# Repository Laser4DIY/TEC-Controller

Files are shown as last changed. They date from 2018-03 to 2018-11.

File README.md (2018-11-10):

# Laser4DIY TEC Controller

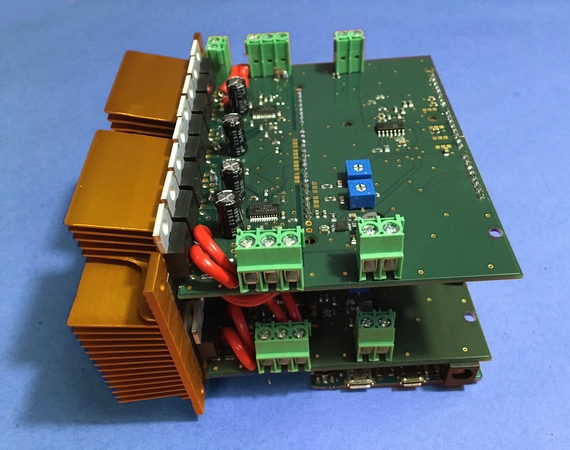
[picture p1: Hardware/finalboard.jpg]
TEC Controller board


This is the repository for the TEC (ThermoElectric Cooling) controller used in the [Laser4DIY project](http://www.laser4diy.org/).

## Specs

* Designed as a shield for the Arduino Due
* 2-channel TEC controller, driving peltier elements up to 106W heat transfer capacity per channel (12A at 15.5V)
* 2 boards can be stacked for a 4-channel TEC controller, driven by a single Arduino Due

## Repository Layout

```
+ Firmware                      firmware directory
| + Firmware.ino                Main Arduino firmware source code file
| + functions_PWM_DAC.ino       source code
| + LICENSE.txt                 license for the fimware
| + main_loop.ino               source code
| + main_setup.ino              source code
+ Hardware                      hardware directory
| + cern_ohl_v_1_2_howto.pdf    Howto for the used hardware license
| + CHANGES.txt                 list of hardware changes
| + finalboard.jpg              photo of the final board
| + LICENSE.txt                 license for the hardware
| + README.txt                  hardware readme
| + schematic.png               schematic
| + TEC-Controller.brd          board layout
| + TEC-Controller.sch          schematic
```

## Documentation

The TEC Controller is documented at [FabLab München Wiki](https://wiki.fablab-muenchen.de/display/WIKI/LASER4DIY+-+TEC+Controller).

## Known Issues

See [Open Issues](https://github.com/Laser4DIY/TEC-Controller/issues?utf8=%E2%9C%93&q=is%3Aopen+is%3Aissue).

## License

The hardware documentation is licensed under CERN OHL v.1.2.

The firmware is licensed under GPLv3.

For details see licensing info in the respective sub directories.

---

Copyright FabLab München e.V. 2018

Laser4DIY is sponsored by the Federal Ministry of Education and Research

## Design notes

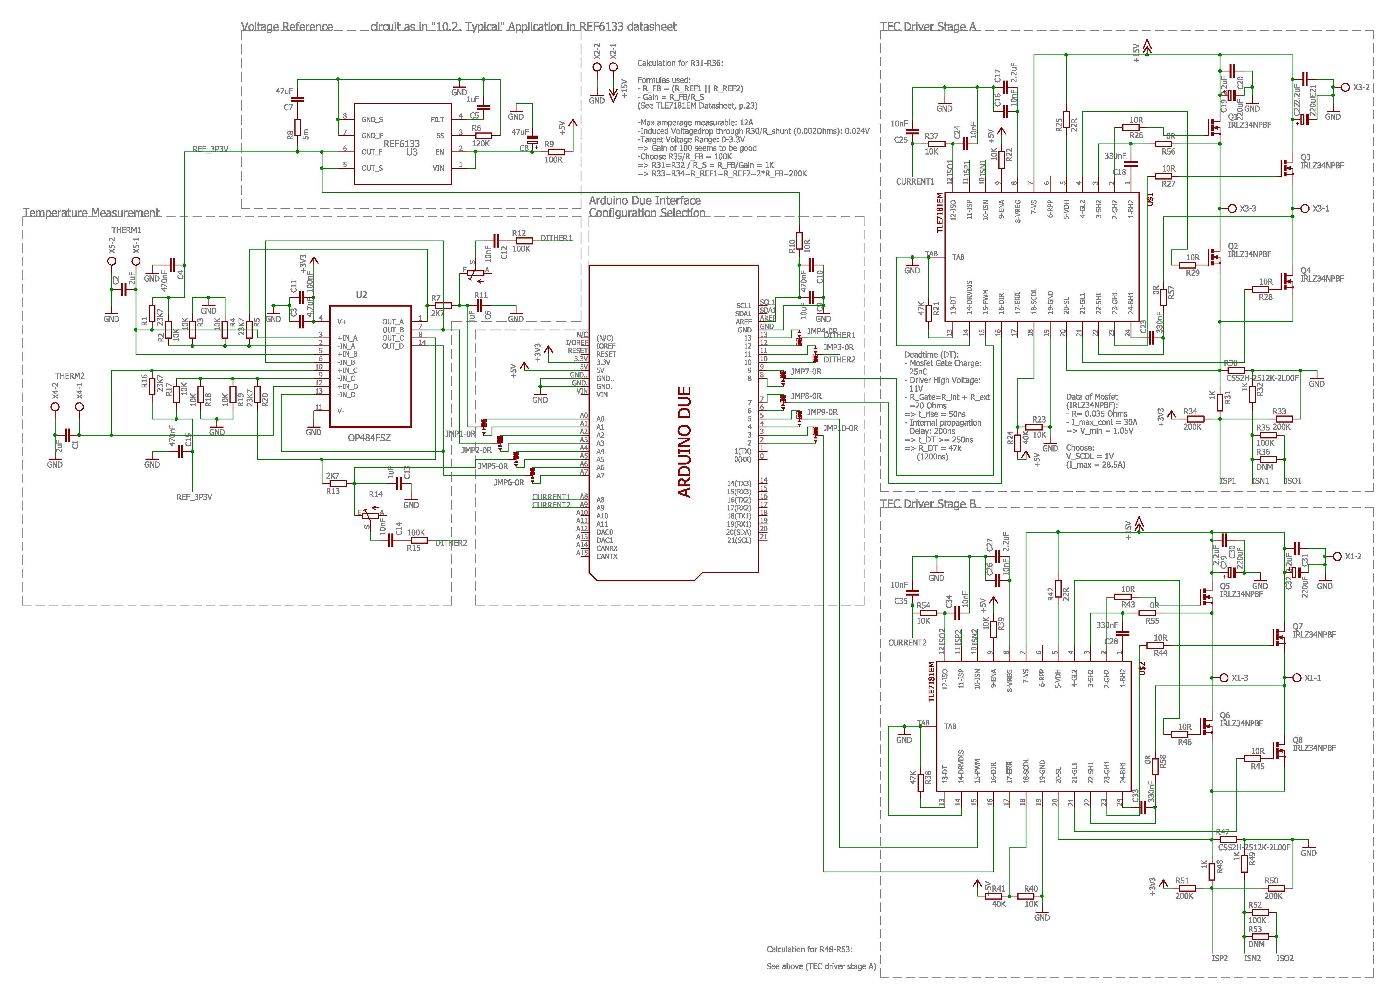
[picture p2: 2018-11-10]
Hardware/schematic.png

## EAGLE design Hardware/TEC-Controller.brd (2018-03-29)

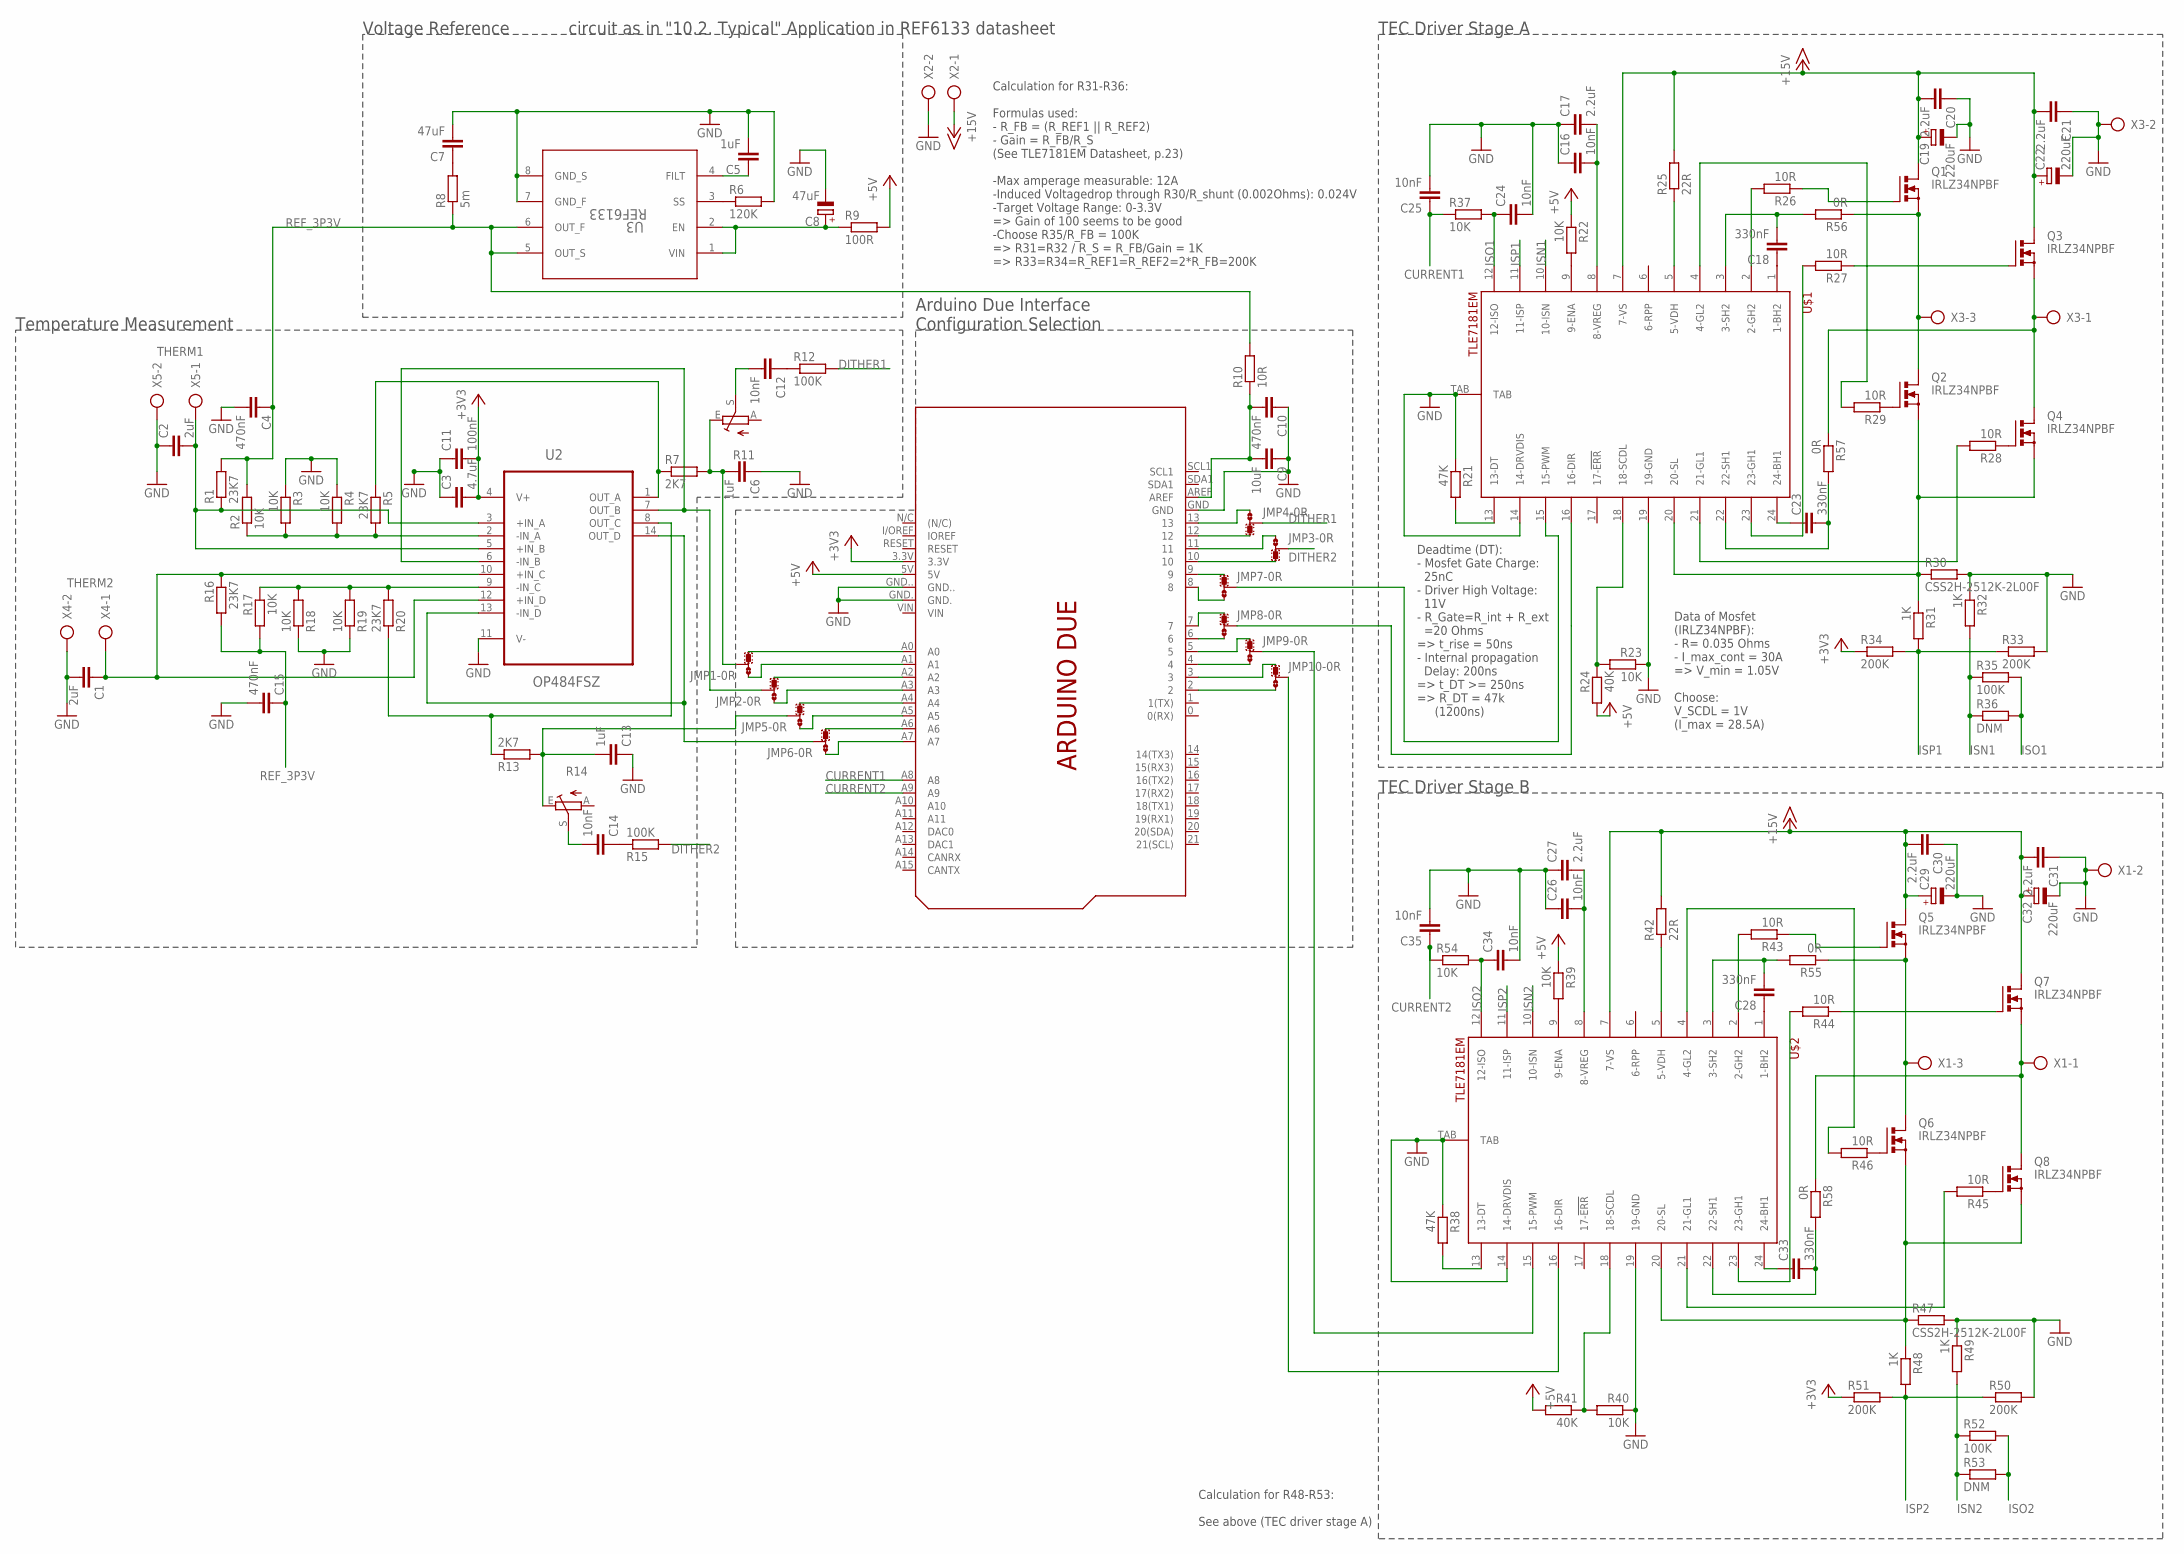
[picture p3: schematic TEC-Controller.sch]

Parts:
C1, C2: 2uF; C0805
C3: 4.7uF; C0603
C4: 470nF; C0805
C5, C6, C13: 1uF; C0805
C7: 47uF; C0603
C8: 47uF; PANASONIC_D
C9: 10uF; C0603
C10, C15: 470nF; C0603
C11: 100nF; C0603
C12, C14: 10nF; C0805
C16, C24, C25: 10nF; C0603K
C17, C20, C21, C30, C31: 2.2uF; C0603K
C18, C23, C28, C33: 330nF; C0603K
C19, C22, C29, C32: 220uF; E2,5-7
C26, C34, C35: 10nF; C0603
C27: 2.2uF; C0603
JMP1, JMP2, JMP3, JMP4, JMP5, JMP6, JMP7, JMP8, JMP9, JMP10: 0R-JUMPA; A0R-JMP
PCB1: ARDUINO_DUE_SHIELD
Q1, Q2, Q3, Q4, Q5, Q6, Q7, Q8: IRLZ34NPBF; TO220BV
R1: 23K7; R0603
R2, R3, R22, R23, R37, R39, R40, R54: 10K; R0603
R4, R17, R18, R19: 10K; R0805
R5, R16, R20: 23K7; R0805
R6: 120K; R0805
R7, R13: 2K7; R0805
R8: 5m; R0603
R9: 100R; R0805
R10, R26: 10R; R0805
R11, R14: TRIM_EU-B64W; B64W
R12, R15: 100K; R0805
R21, R38: 47K; R0603
R24, R41: 40K; R0603
R25, R42: 22R; R0603
R27, R28, R29, R43, R44, R45, R46: 10R; 0204/7
R30, R47: CSS2H-2512K-2L00F; R2512
R31, R32, R48, R49: 1K; R0603
R33, R34, R50, R51: 200K; R0603
R35, R52: 100K; R0603
R36, R53: DNM; R0603
R55, R56, R57, R58: 0R; 0204/7
U2: OP484FSZ; SOIC127P600X175-14N
U3: REF6133; DGK0008A_N
U$1, U$2: TLE7181EM; PG-SSOP-24-4
X1, X3: AK500/3
X2, X4, X5: AK500/2

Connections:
+3V3: C3.2, C11.2, PCB1.3.3V, R34.1, R51.1, U2.4 (V+)
+5V: PCB1.5V, R9.2, R22.1, R24.2, R39.1, R41.2
+15V: C19.+, C20.2, C21.2, C22.+, C29.+, C30.2, C31.2, C32.+, Q1.D, Q3.D, Q5.D, Q7.D, R25.2, R42.2, U$1.7 (7-VS), U$2.7 (7-VS), X2.1
CURRENT1: C25.1, PCB1.A8, R37.1
CURRENT2: C35.1, PCB1.A9, R54.1
DITHER1: JMP4.2, R12.2
DITHER2: JMP3.2, R15.2
GND: C1.2, C2.1, C3.1, C4.2, C5.2, C6.1, C7.2, C8.-, C9.1, C10.1, C11.1, C13.1, C15.2, C16.1, C17.1, C19.-, C20.1, C21.1, C22.-, C24.2, C25.2, C26.1, C27.1, C29.-, C30.1, C31.1, C32.-, C34.2, C35.2, PCB1.GND, PCB1.GND., PCB1.GND.., R3.1, R4.1, R6.2, R18.1, R19.1, R21.1, R23.1, R30.2, R32.1, R33.2, R38.1, R40.1, R47.2, R49.1, R50.2, U2.11 (V-), U3.7 (GND_F), U3.8 (GND_S), U$1.14 (14-DRVDIS), U$1.19 (19-GND), U$1.TAB, U$2.14 (14-DRVDIS), U$2.19 (19-GND), U$2.TAB, X1.2, X2.2, X3.2, X4.2, X5.2
ISN1: R32.2, R35.1, R36.1, U$1.10 (10-ISN)
ISN2: R49.2, R52.1, R53.1, U$2.10 (10-ISN)
ISO1: C24.1, R35.2, R36.2, R37.2, U$1.12 (12-ISO)
ISO2: C34.1, R52.2, R53.2, R54.2, U$2.12 (12-ISO)
ISP1: R31.2, R33.1, R34.2, U$1.11 (11-ISP)
ISP2: R48.2, R50.1, R51.2, U$2.11 (11-ISP)
unnamed: C28.2, R55.2, U$2.3 (3-SH2)
unnamed: C2.2, R1.1, U2.3 (+IN_A), U2.5 (+IN_B), X5.1
unnamed: C1.1, R16.1, U2.10 (+IN_C), U2.12 (+IN_D), X4.1
unnamed: R2.1, R3.2, R4.2, R5.2, U2.2 (-IN_A)
unnamed: C18.2, R56.2, U$1.3 (3-SH2)
unnamed: JMP2.2, U2.6 (-IN_B), U2.7 (OUT_B)
unnamed: R5.1, R7.1, U2.1 (OUT_A)
unnamed: JMP4.3, PCB1.12
unnamed: JMP1.3, PCB1.A0
unnamed: C5.1, U3.4 (FILT)
unnamed: R6.1, U3.3 (SS)
unnamed: JMP1.1, PCB1.A1
unnamed: JMP2.3, PCB1.A2
unnamed: C6.2, JMP1.2, R7.2, R11.E
unnamed: JMP2.1, PCB1.A3
unnamed: C7.1, R8.2
unnamed: C8.+, R9.1, U3.1 (VIN), U3.2 (EN)
unnamed: C9.2, C10.2, PCB1.AREF, R10.1
unnamed: C12.2, R11.S
unnamed: JMP3.1, PCB1.11
unnamed: JMP4.1, PCB1.13
unnamed: JMP7.1, PCB1.9
unnamed: JMP3.3, PCB1.10
unnamed: C12.1, R12.1
unnamed: R17.1, R18.2, R19.2, R20.2, U2.9 (-IN_C)
unnamed: R13.1, R20.1, U2.8 (OUT_C)
unnamed: C13.2, JMP5.2, R13.2, R14.E
unnamed: C14.1, R15.1
unnamed: C14.2, R14.S
unnamed: JMP5.3, PCB1.A4
unnamed: JMP5.1, PCB1.A5
unnamed: JMP7.3, PCB1.8
unnamed: JMP6.3, PCB1.A6
unnamed: JMP6.1, PCB1.A7
unnamed: JMP6.2, U2.13 (-IN_D), U2.14 (OUT_D)
unnamed: JMP8.1, PCB1.7
unnamed: JMP8.3, PCB1.6
unnamed: JMP7.2, U$1.15 (15-PWM)
unnamed: JMP8.2, U$1.16 (16-DIR)
unnamed: R21.2, U$1.13 (13-DT)
unnamed: R23.2, R24.1, U$1.18 (18-SCDL)
unnamed: R22.2, U$1.9 (9-ENA)
unnamed: R25.1, U$1.5 (5-VDH)
unnamed: C16.2, C17.2, U$1.8 (8-VREG)
unnamed: R26.2, U$1.2 (2-GH2)
unnamed: Q1.G, R26.1
unnamed: Q1.S, Q2.D, R56.1, X3.3
unnamed: C18.1, U$1.1 (1-BH2)
unnamed: R27.2, U$1.23 (23-GH1)
unnamed: Q3.G, R27.1
unnamed: Q3.S, Q4.D, R57.1, X3.1
unnamed: C23.1, U$1.24 (24-BH1)
unnamed: Q4.G, R28.1
unnamed: Q2.G, R29.1
unnamed: R29.2, U$1.4 (4-GL2)
unnamed: R28.2, U$1.21 (21-GL1)
unnamed: Q2.S, Q4.S, R30.1, R31.1, U$1.20 (20-SL)
unnamed: JMP9.2, U$2.15 (15-PWM)
unnamed: C33.2, R58.2, U$2.22 (22-SH1)
unnamed: JMP10.2, U$2.16 (16-DIR)
unnamed: R38.2, U$2.13 (13-DT)
unnamed: R39.2, U$2.9 (9-ENA)
unnamed: R40.2, R41.1, U$2.18 (18-SCDL)
unnamed: C26.2, C27.2, U$2.8 (8-VREG)
unnamed: R42.1, U$2.5 (5-VDH)
unnamed: R43.2, U$2.2 (2-GH2)
unnamed: Q5.S, Q6.D, R55.1, X1.3
unnamed: C28.1, U$2.1 (1-BH2)
unnamed: Q5.G, R43.1
unnamed: R44.2, U$2.23 (23-GH1)
unnamed: Q7.G, R44.1
unnamed: Q7.S, Q8.D, R58.1, X1.1
unnamed: C33.1, U$2.24 (24-BH1)
unnamed: Q8.G, R45.1
unnamed: Q6.G, R46.1
unnamed: R46.2, U$2.4 (4-GL2)
unnamed: R45.2, U$2.21 (21-GL1)
unnamed: Q6.S, Q8.S, R47.1, R48.1, U$2.20 (20-SL)
unnamed: C23.2, R57.2, U$1.22 (22-SH1)
unnamed: JMP9.1, PCB1.5
unnamed: JMP9.3, PCB1.4
unnamed: JMP10.1, PCB1.3
unnamed: JMP10.3, PCB1.2
REF_3P3V: C4.1, C15.1, R1.2, R2.2, R8.1, R10.2, R16.2, R17.2, U3.5 (OUT_S), U3.6 (OUT_F)

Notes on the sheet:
THERM1
THERM2
Voltage Reference
Temperature Measurement
Arduino Due Interface Configuration Selection
TEC Driver Stage A
TEC Driver Stage B
circuit as in "10.2. Typical" Application in REF6133 datasheet
Calculation for R31-R36: Formulas used: - R_FB = (R_REF1 || R_REF2) - Gain = R_FB/R_S (See TLE7181EM Datasheet, p.23) -Max amperage measurable: 12A -Induced Voltagedrop through R30/R_shunt (0.002Ohms): 0.024V -Target Voltage Range: 0-3.3V => Gain of 100 seems to be good -Choose R35/R_FB = 100K => R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
Calculation for R48-R53: See above (TEC driver stage A)
Data of Mosfet (IRLZ34NPBF): - R= 0.035 Ohms - I_max_cont = 30A => V_min = 1.05V Choose: V_SCDL = 1V (I_max = 28.5A)
Deadtime (DT): - Mosfet Gate Charge: 25nC - Driver High Voltage: 11V - R_Gate=R_int + R_ext =20 Ohms => t_rise = 50ns - Internal propagation Delay: 200ns => t_DT >= 250ns => R_DT = 47k (1200ns)

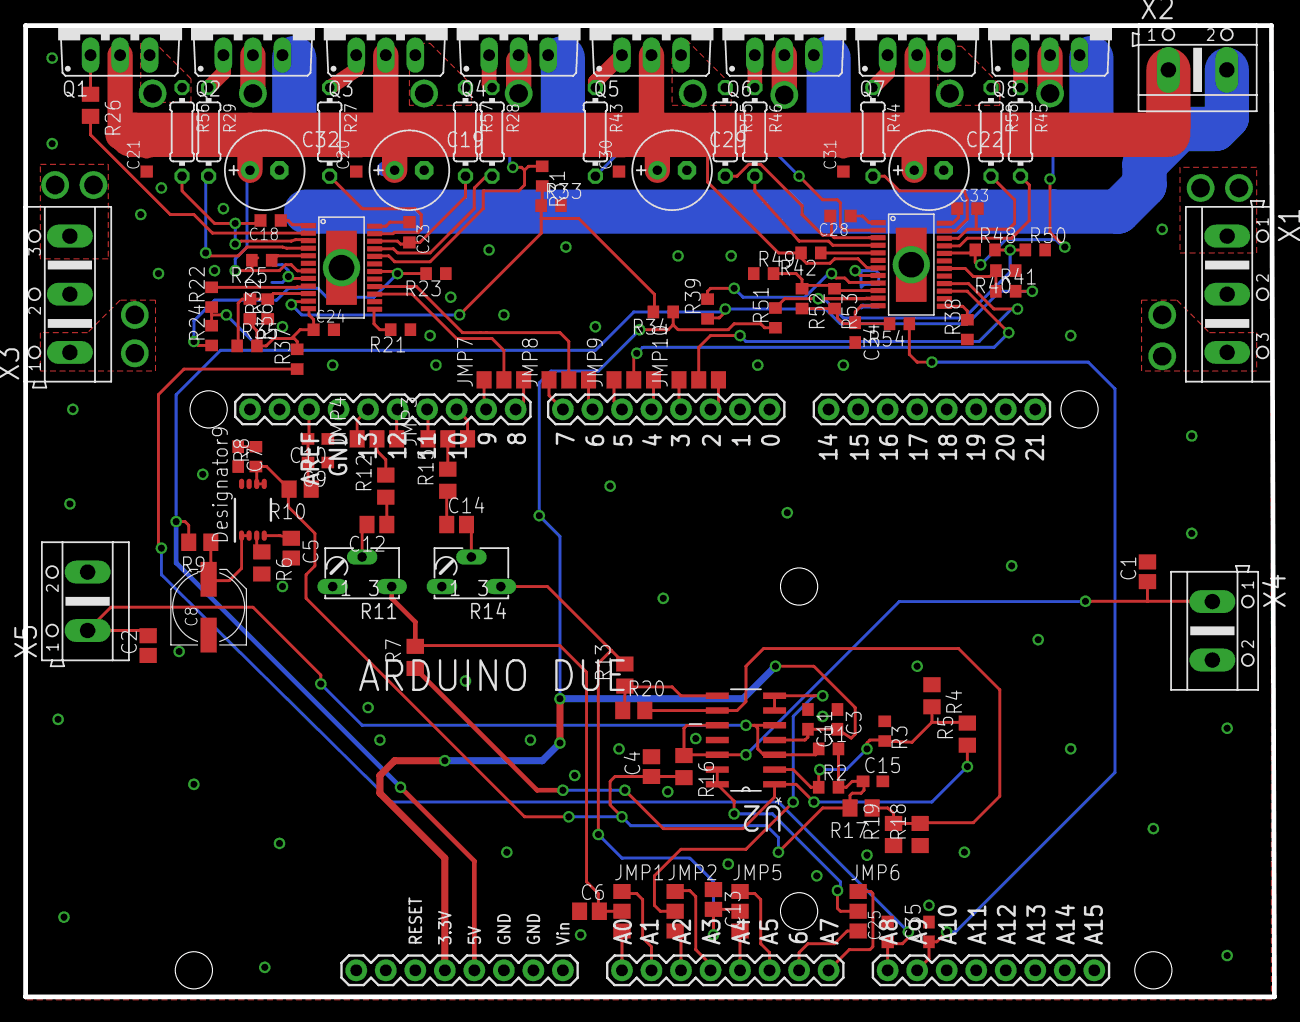
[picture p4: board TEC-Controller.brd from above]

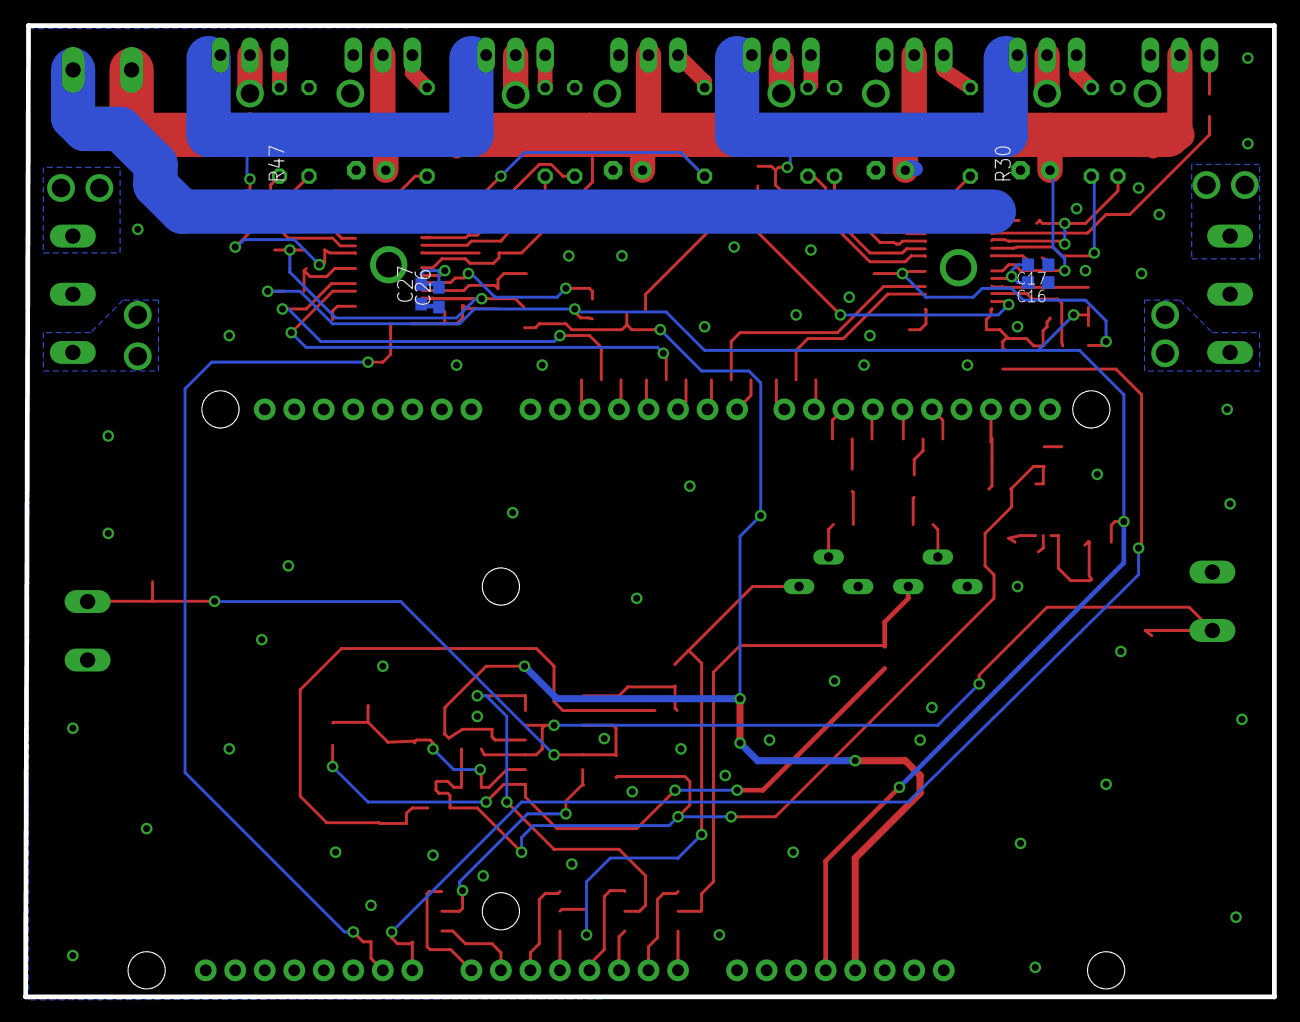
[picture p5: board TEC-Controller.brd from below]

Board: 2 copper layers, 107.4 x 83.6 mm, 121 parts (6 on the bottom side), 98 nets.

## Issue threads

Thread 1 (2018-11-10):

LC filter for output

drayde, 2018-11-10:
For long term use of peltier elements driven by PWM a LC filter to smooth out the voltage is needed. This reduces the internal stress in the module and therefore prolongs the lifetime.

A suitable LC filter could consist out of a 22uH inductor and a 100uF capacitor.
As a work around this was added externally at the moment. It should be added to the board in future revisions.

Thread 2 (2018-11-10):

R27 hard to solder - could cause mosfet to be disabled

drayde, 2018-11-10:
Resistor R27 is directly placed over the shunt resistor R30, which can cause a bridge between ground and the related MOSFET gate, which causes the MOSFET to be disabled until the short is removed.
This can be circumvented by carefully soldering R27 in. In a next revision of the board design this will be changed

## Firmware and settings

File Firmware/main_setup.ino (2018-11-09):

/*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
    You should have received a copy of the GNU General Public License
    along with this program.  If not, see <https://www.gnu.org/licenses/>.
*/

//===================== setup ==========================================


void setup ()
{
  Serial.begin(115200);   // serial I/O
  while (!Serial) {
    ; // wait for serial port to connect. Needed for native USB port only
  }
  Serial.println("SETUP START");
  eep.begin_spi(EEPROM_CSPIN);
  
  //setup registers and pins for PWM
  pinMode(CHANNEL1_PWM_PIN, OUTPUT);
  pinMode(CHANNEL2_PWM_PIN, OUTPUT);
  pinMode(CHANNEL1_DITHER_PIN, OUTPUT);
  analogWriteResolution(12); //increase to 12 bit PWM resolution
  //ATTENTION! pwm+timer frequency has to be changed to 20kHz at "C:\Users\Work\AppData\Local\Arduino15\packages\arduino\hardware\sam\1.6.11\variants\arduino_due_x\variant.h"

  //prepare digital pins
  pinMode(CHANNEL1_DIR_PIN, OUTPUT);
  pinMode(CHANNEL2_DIR_PIN, OUTPUT);
  pinMode(LED_PIN, OUTPUT);
  digitalWrite(CHANNEL1_DIR_PIN, LOW); 
  digitalWrite(CHANNEL2_DIR_PIN, LOW); 
  analogWrite(CHANNEL1_PWM_PIN, midval);  //set to zero PWM drive
  analogWrite(CHANNEL2_PWM_PIN, midval);  //set to zero PWM drive
  Serial.println("TEST2");
  digitalWrite(CHANNEL1_DIR_PIN, HIGH);
  digitalWrite(CHANNEL2_DIR_PIN, HIGH);
  pinMode(SETPOINT_PIN, INPUT);
 //----------------------------------------------------------------------------
  //check if there are settings stored in EEprom, if not or zero, replace by defaults
  
  //if not use default values
  if ((int)settings.ee_kp < 10) {
    kp = def_kp; ki = def_ki; kd = def_kd; 
  } else {
    kp = settings.ee_kp; ki = settings.ee_ki; kd = settings.ee_kd;
  }

  if ((int)settings.ee_currentzero< 1) {
    currentzero=def_currentzero;
  } else {
    currentzero= settings.ee_currentzero;
  }

    if ((int)settings.ee_currentlimit< 1) {
    currentlimit=def_currentlimit;
  } else {
    currentlimit= settings.ee_currentlimit;
  }
  
    //set drive for max current
  if ((int)settings.ee_maxval < 1) {
    maxval = def_maxval;
  } else {
    maxval = settings.ee_maxval;
  }
   minval = framesize - maxval;

//----------------------------------------------------------------------------
 //setup PID

  CHANNEL1_PID.SetOutputLimits(0, 4095);             //limits for 12bit PWM  
  CHANNEL1_PID.SetMode(AUTOMATIC); //turn the PID on
  lastTime = millis() - SampleTime; //shift to force PID immedially after read

//----------------------------------------------------------------------------


   Input = TSetpoint;
   Serial.println("SETUP DONE");
}

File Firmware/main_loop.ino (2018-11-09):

/*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
    You should have received a copy of the GNU General Public License
    along with this program.  If not, see <https://www.gnu.org/licenses/>.
*/

//========================= main loop ========================

void loop ()
{
  //randomizing the read time avoids commensurability oscill.

  now = millis();
  randomtime = (unsigned) random(3 * SampleTime / 4  ); //!!!!!!
  timeChange = (now - lastTime);
  if (timeChange >= randomtime) {

    //----------------------------- main ADC reads------------
    current = readPWMcurrent();
    Input = volt2temp(4 * ReadAnalogAverage(CHANNEL1_ADC1_PIN, 256));
    int setpoint_adc = ReadAnalogAverage(SETPOINT_PIN, 256);
    TSetpoint = 10.00 + setpoint_adc / 50.0;
    //diagnosis output over serial every second (Input, Setpoint, Output)
    if (millis() - lastMessageTime > 1000) {
      Serial.print("I: "); Serial.print(Input); Serial.print(", S:"); Serial.print(TSetpoint); Serial.print(", O: "); Serial.println(Output);
      lastMessageTime = millis();
    }
    lastTime = now;
  }

  //do main PID computation
  CHANNEL1_PID.Compute();

  if  (isfault) {
    Serial.println("FAULT");
    digitalWrite(CHANNEL1_PWM_PIN, HIGH);
    digitalWrite(CHANNEL2_PWM_PIN, HIGH);
  } else {
    analogWrite(CHANNEL1_PWM_PIN, Output);
    analogWrite(CHANNEL2_PWM_PIN, Output);
  }

  //------ periodic error capture---------------------

  if (millis() > periodicTimeCheck)
  {
    //check if thermistor temp is outside rangePID
    Tprotect = 4 * ReadAnalogAverage(protecttemppin, 2);
    int tempprotect = volt2temp(100);

    //do checks and shutdown if needed
    if (Tprotect < catchuppertemplimit || Tprotect > catchlowertemplimit   //thermistor open or shorted
        ||  abs(current) > 1.5 * currentlimit
       ) {
      Serial.print(Tprotect);
#if  drv8872                              //shutdown timer 1
      TCCR1B = 0x00;
      digitalWrite(CHANNEL1_PWM_PIN, LOW);
      digitalWrite(CHANNEL2_PWM_PIN, LOW);
#endif
      isfault = true;
      digitalWrite(LED_PIN, HIGH); //turn ARDUINO LED on in case of error
    } else {
      if (isfault) {
        digitalWrite(CHANNEL1_DIR_PIN, HIGH);
        digitalWrite(CHANNEL2_DIR_PIN, HIGH);
#if  drv8872
        setupPWM16() ;      //restart PWM
#endif
        isfault = false;
        digitalWrite(LED_PIN, LOW); //turn ARDUINO LED on in case of no error
      }
    }
    periodicTimeCheck += 250;
  }
  //end periodic serial IO and error capture, do it every 0.25sec


} //end main loop

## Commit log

2018-03-29 initial commit
    This is a testversion
    [TEC-Controller.brd, TEC-Controller.sch]
2018-11-10 added schematic as png

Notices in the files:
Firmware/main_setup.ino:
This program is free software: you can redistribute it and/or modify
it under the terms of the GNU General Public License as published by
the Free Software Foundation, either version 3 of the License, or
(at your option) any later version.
